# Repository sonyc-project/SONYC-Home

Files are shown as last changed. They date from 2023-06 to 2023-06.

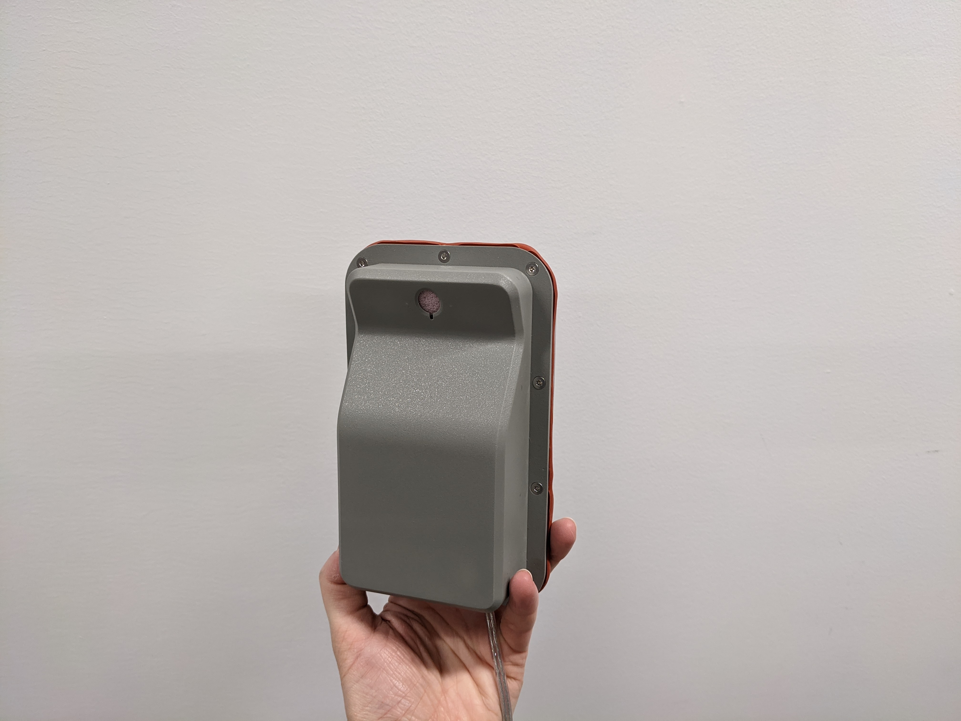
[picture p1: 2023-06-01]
Hardware/History/Assembly Photos/PXL_20201028_211720982.jpg

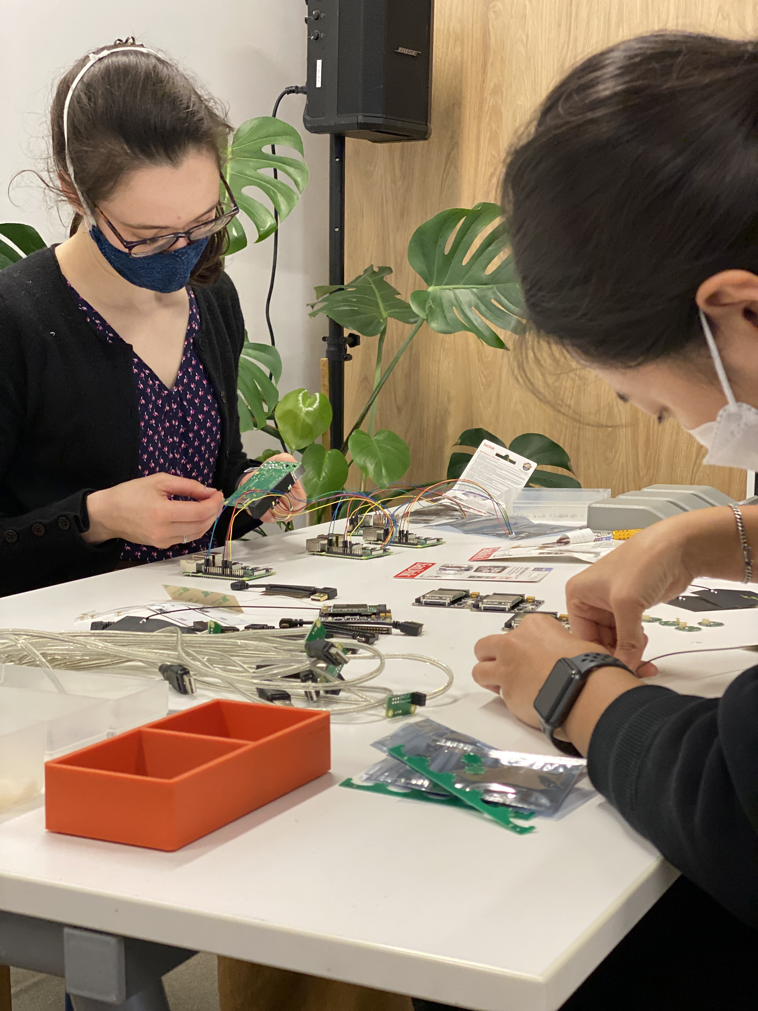
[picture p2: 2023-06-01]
Hardware/History/Assembly Photos/IMG_3674.jpeg

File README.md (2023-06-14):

# SONYC Home Project Summary
The SONYC Home project aims to address the issue of urban noise pollution, which poses a threat to the quality of life and public health of urban inhabitants. The World Health Organization (WHO) has documented various adverse health effects caused by noise pollution, including hearing impairment, interference with speech communication, disturbance of rest and sleep, mental health and performance effects, residential behavior and annoyance, and interference with intended activities.

In New York City (NYC), noise is monitored through the 311 civil complaint service, which has received close to 5 million noise-related complaints to date, outnumbering any other complaint type. However, this service has limitations in terms of validating and resolving complaints in a timely manner due to resource constraints and the transient nature of noise sources.

To address these challenges, the SONYC Home project has developed a solution that involves deploying a fleet of noise sensors on the exteriors of NYC residents' windows. These sensors provide accurate decibel measurements, utilize machine learning algorithms for sound source identification, and enhance noise reporting to city agencies responsible for enforcing noise regulations. Residents can interact with the sensor data through an app, which includes visualizations of decibel data over time and allows for human-in-the-loop machine learning.

The deployment of sensor networks in urban settings presents technical and logistical challenges. The SONYC Home sensors rely on existing power outlets and utilize LTE cellular connectivity to overcome limitations in power and networking infrastructure. Mounting the sensors on residential windows allows for proximity to complainants and easy access to power outlets.

The ideal domestic noise monitoring sensor for the SONYC Home project should have features such as simple deployment, unintrusiveness, low maintenance, weather resistance, data privacy, accessible data insights/visualization, and user interactivity.

The SONYC Home sensor network consists of remote acoustic sensors deployed outside the apartments of participants with noise issues. These sensors transmit data to central servers, where it is securely stored and made available to users and relevant city agencies through web browsers. The sensor design prioritizes usability and utility, with a single board computer, cellular connectivity, custom calibrated acoustic front-end, and a custom housing with a heat sink to address overheating issues.

The mounting of the sensors is designed to be user-friendly, allowing users to easily mount the devices on their windows with adhesive strips. The sensors undergo physical stress testing to ensure they can withstand environmental conditions and remain securely mounted. The sensors are equipped with a custom microphone board, featuring a high-performance digital MEMS microphone that captures the full frequency range of urban sound. The microphone is calibrated for accuracy, and measures are taken to protect it from water damage.

The software running on the SONYC Home sensors extracts relevant information from the environment, including overall sound level and machine learning classifications. The collected audio samples are used for identification purposes and can contribute to the development of advanced machine learning algorithms. Privacy is maintained by sparse sampling of audio and ensuring conversations cannot be reconstructed.

Overall, the SONYC Home project provides a comprehensive solution for monitoring and mitigating urban noise issues, combining advanced sensor technology, machine learning, and user engagement to improve the quality of life for urban inhabitants.

This repository is a centralized hub for all resources related to the project. It consists of three main directories, each dedicated to a specific component of the system:

### [Hardware](<./Hardware>)
The **Hardware** directory stores hardware design files, including schematics, PCB layouts, and relevant documentation.

### [Node software](<./Node software>)
The **Node software** directory contains firmware, drivers, and software modules for the noise sensor nodes. These components capture noise data, implement machine listening algorithms and transmit it to the central server.

### [Server software](<./Server software>)
The **Server software** directory houses the software components running on the project server. It includes backend infrastructure, data processing algorithms, database management systems, and web interfaces for data visualization and analysis.

**This is all a work in progress so will be updated as this content is compiled**

------------------------------------------------------------------------------------------------------------------------
Shield: [][cc-by-nc-sa]

This work is licensed under a
[Creative Commons Attribution-NonCommercial-ShareAlike 4.0 International License][cc-by-nc-sa].

[][cc-by-nc-sa]

[cc-by-nc-sa]: http://creativecommons.org/licenses/by-nc-sa/4.0/
[cc-by-nc-sa-image]: https://licensebuttons.net/l/by-nc-sa/4.0/88x31.png
[cc-by-nc-sa-shield]: https://img.shields.io/badge/License-CC%20BY--NC--SA%204.0-lightgrey.svg

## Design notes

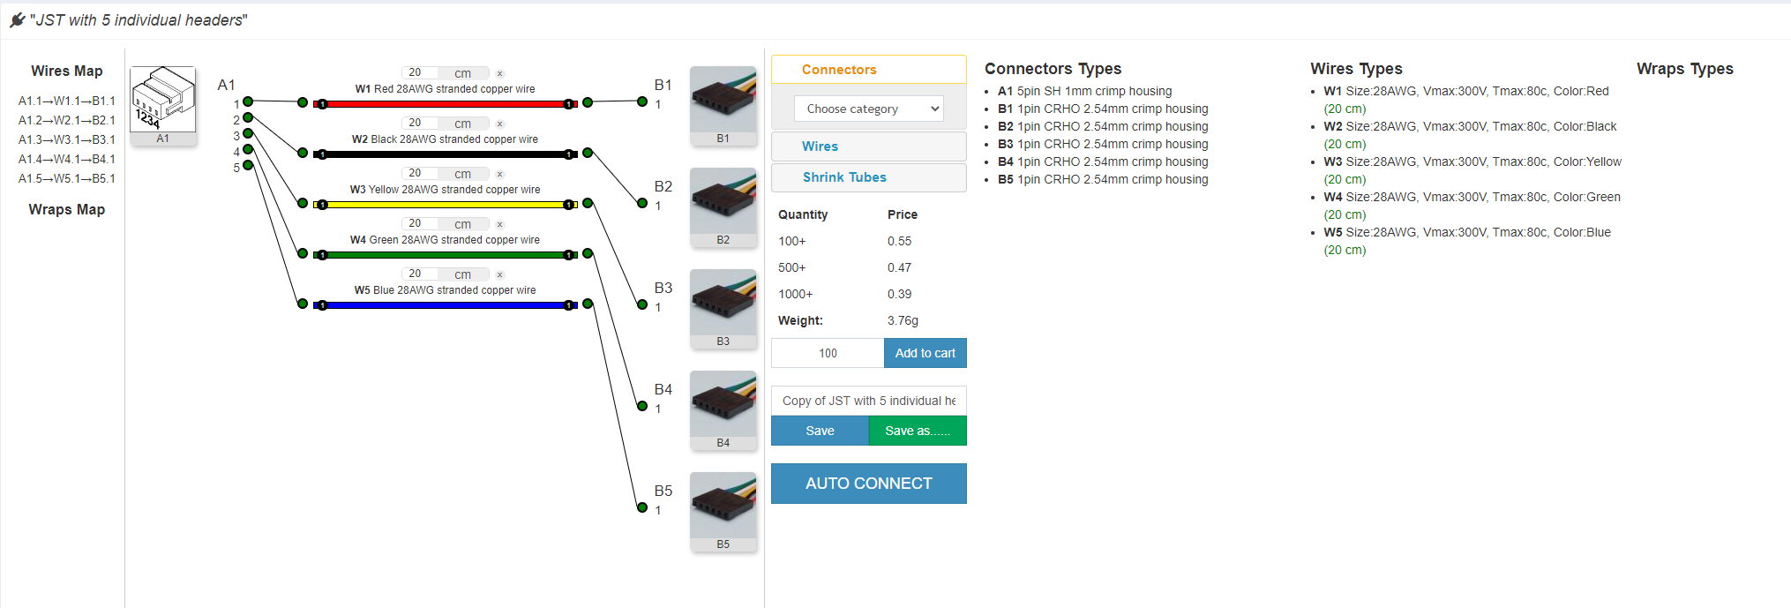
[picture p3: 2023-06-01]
Hardware/Design Files/Drawings/Mic-Cable-custom.png

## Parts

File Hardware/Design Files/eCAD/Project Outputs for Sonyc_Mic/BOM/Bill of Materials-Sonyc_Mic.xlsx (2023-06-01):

Designator | Quantity | Description | Comment | Value | Voltage | Footprint
C1 | 1 | CAP 0402 CERAMIC 100n 16V ±10% X7R | 100n | 100n | 16V | 0402CAP
CN1 | 1 | JST Connector Header Surface Mount 5 position 0.039" (1.00mm) | BM05B-SRSS-TB |  |  | CON5_BM05B-SRSS-TB
MK1 | 1 | MICROPHONE MEMS DIGITAL I2S OMNI | ICS43432 | ICS43432 |  | ICS43432
R1, R2, R3 | 3 | RES 0402 0.063W ±1% THICK FILM | 15R | 15R | 50V | 0402 | REPLACE WITH 0ohm resistor!

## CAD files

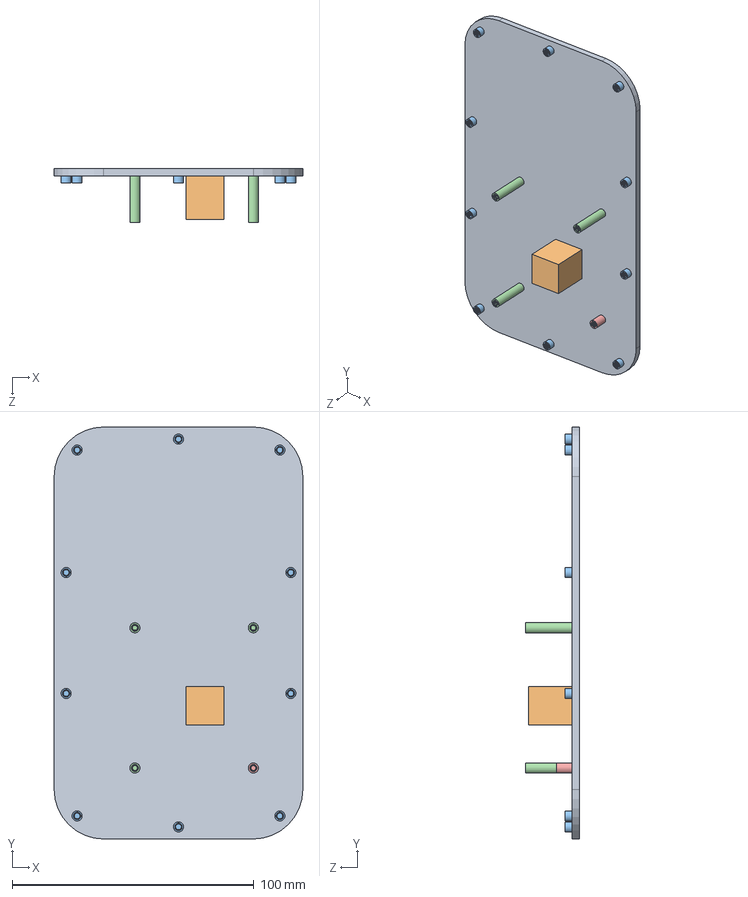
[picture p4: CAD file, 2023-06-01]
Hardware/Design Files/Solidworks CAD/SONYC-SW-database/BACK-PLATE-ASSEMBLY.SLDASM
102.9 x 170.4 x 22.2 mm
Back-Plate
SONYC-Heat-sink-block
93090A571_PRESS-FIT FEMALE ROUND STANDOFFS x 10
93090A554_PRESS-FIT FEMALE ROUND STANDOFFS x 3
93090A430_PRESS-FIT FEMALE ROUND STANDOFFS

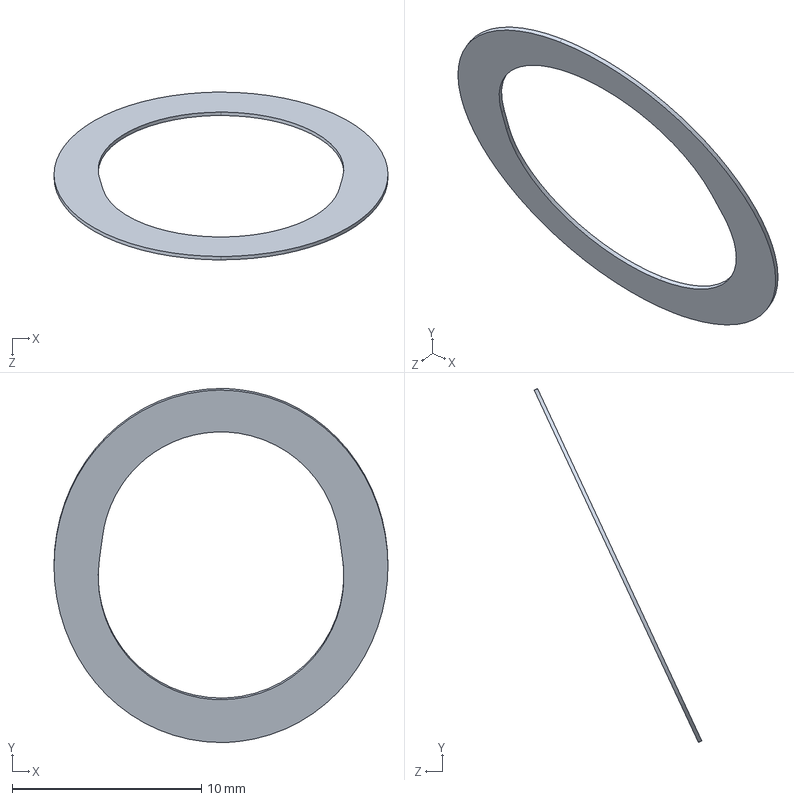
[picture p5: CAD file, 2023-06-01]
Hardware/Design Files/STEP files/SONYC-Porelle-membrane rev1.STEP
17.6 x 18.7 x 8.87 mm

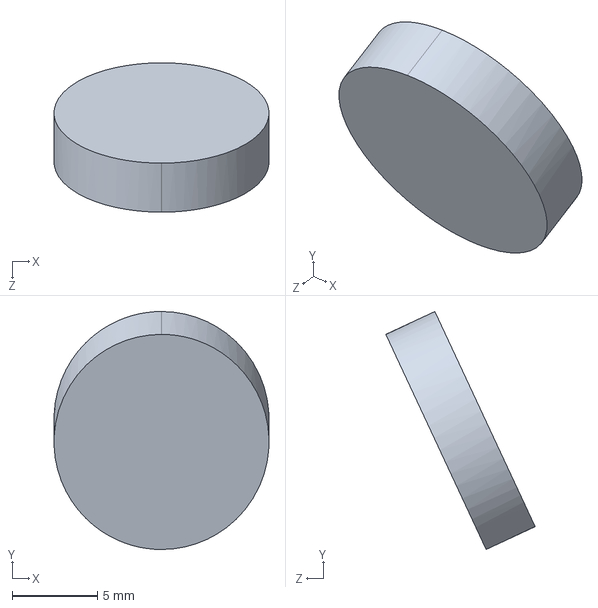
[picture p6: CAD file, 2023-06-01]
Hardware/Design Files/STEP files/SONYC_foam-windscreen rev.STEP
12.6 x 14.0 x 8.76 mm

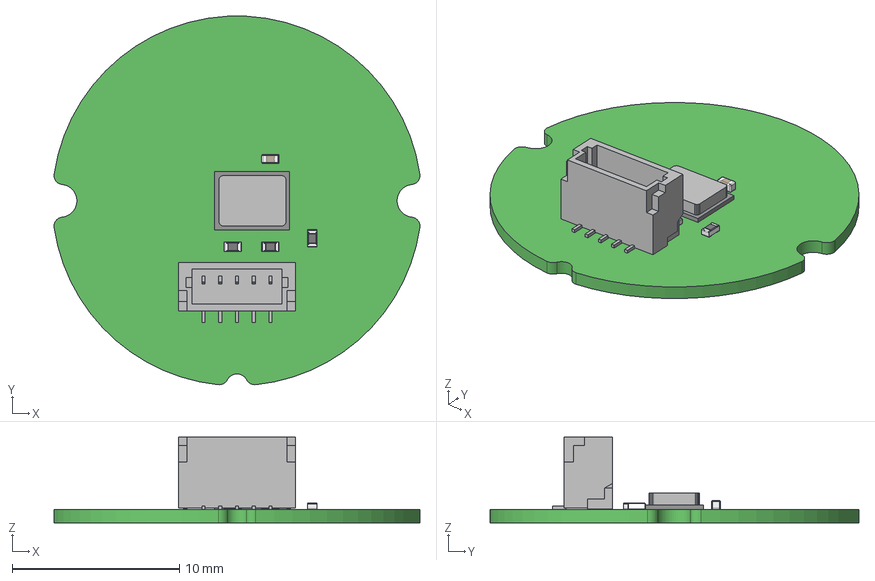
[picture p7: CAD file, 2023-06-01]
Hardware/Design Files/eCAD/Project Outputs for Sonyc_Mic/ExportSTEP/Sonyc_Mic.step
21.9 x 22.0 x 5.13 mm
Extruded x 2
BM05B-SRSS-TB_RGB8421504

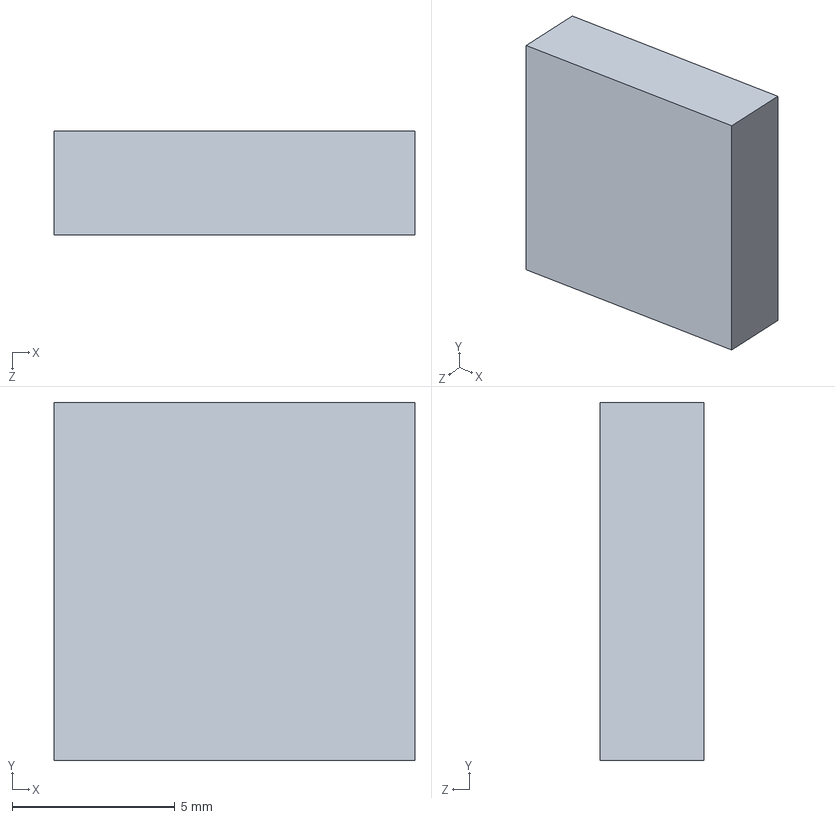
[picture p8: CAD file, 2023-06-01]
Hardware/Design Files/STEP files/SONYC_gasket_power-cable rev.STEP
11.1 x 11.0 x 3.18 mm

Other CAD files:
Hardware/Design Files/STEP files/BACK-PLATE-ASSEMBLY rev4.STEP
Hardware/Design Files/eCAD/Project Outputs for Sonyc_Mic/ExportSTEP/Board.sldasm
Hardware/Design Files/eCAD/Project Outputs for Sonyc_Mic/ExportSTEP/MK1.sldasm
Hardware/Design Files/eCAD/Project Outputs for Sonyc_Mic/ExportSTEP/R2.sldasm
Hardware/Design Files/eCAD/Project Outputs for Sonyc_Mic/ExportSTEP/RESC-0402.sldasm
Hardware/Design Files/eCAD/Project Outputs for Sonyc_Mic/ExportSTEP/R3.sldasm
Hardware/Design Files/eCAD/Project Outputs for Sonyc_Mic/ExportSTEP/CN1.sldasm
Hardware/Design Files/eCAD/Project Outputs for Sonyc_Mic/ExportSTEP/C1.sldasm
Hardware/Design Files/eCAD/Project Outputs for Sonyc_Mic/ExportSTEP/R1.sldasm
Hardware/Design Files/eCAD/Project Outputs for Sonyc_Mic/ExportSTEP/CAPC-0402-T0.55-BN.sldasm
Hardware/Design Files/eCAD/Project Outputs for Sonyc_Mic/AutoCAD PCB/Sonyc_Mic.DWG
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

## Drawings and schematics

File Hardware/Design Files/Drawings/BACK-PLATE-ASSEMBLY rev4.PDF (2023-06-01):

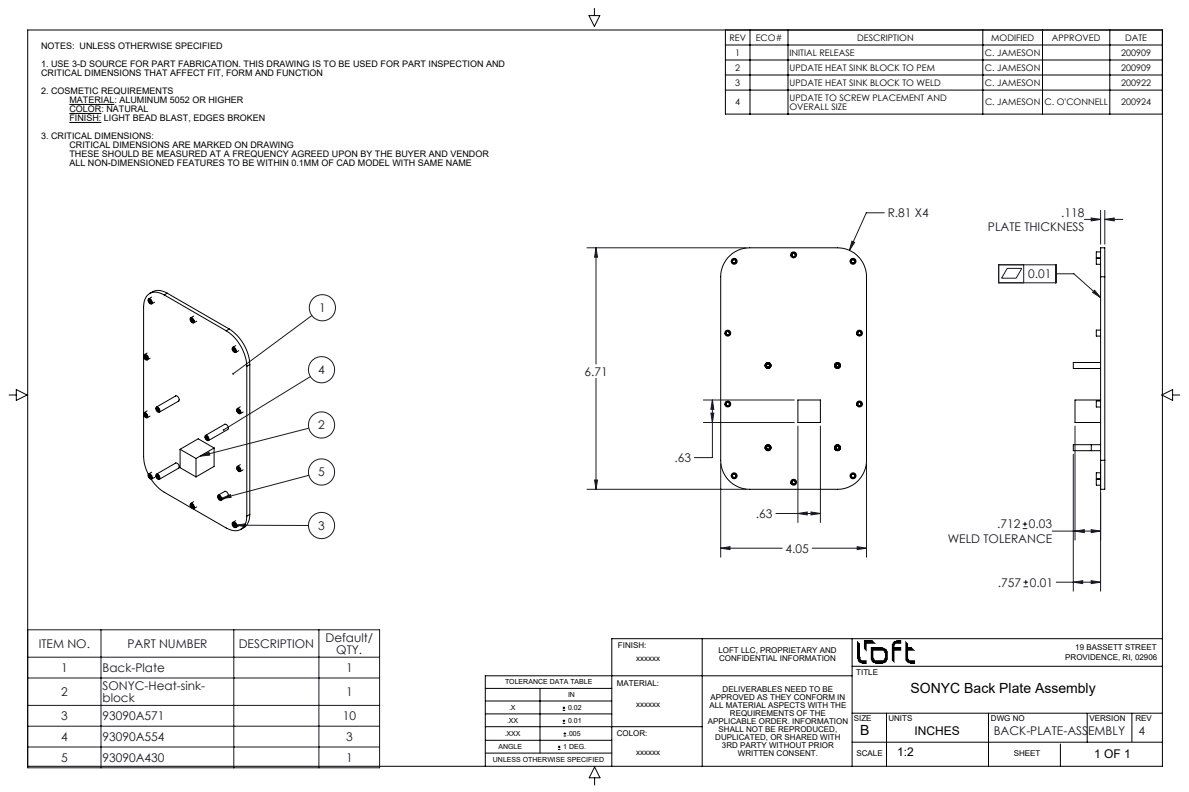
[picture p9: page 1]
WELD TOLERANCE; PLATE THICKNESS; SIZE; UNITS; DWG NO; REV; ANGLE; 1 DEG.; UNLESS OTHERWISE SPECIFIED; 19 BASSETT STREET PROVIDENCE, RI, 02906

REV | ECO# | DESCRIPTION | MODIFIED | APPROVED | DATE
1 | | INITIAL RELEASE | C. JAMESON | | 200909
2 | | UPDATE HEAT SINK BLOCK TO PEM | C. JAMESON | | 200909
3 | | UPDATE HEAT SINK BLOCK TO WELD | C. JAMESON | | 200922
4 | | UPDATE TO SCREW PLACEMENT AND OVERALL SIZE | C. JAMESON | C. O'CONNELL | 200924

NOTES: UNLESS OTHERWISE SPECIFIED
1. USE 3-D SOURCE FOR PART FABRICATION. THIS DRAWING IS TO BE USED FOR PART INSPECTION AND
CRITICAL DIMENSIONS THAT AFFECT FIT, FORM AND FUNCTION
2. COSMETIC REQUIREMENTS
MATERIAL: ALUMINUM 5052 OR HIGHER
COLOR: NATURAL
FINISH: LIGHT BEAD BLAST, EDGES BROKEN
3. CRITICAL DIMENSIONS:
CRITICAL DIMENSIONS ARE MARKED ON DRAWING
THESE SHOULD BE MEASURED AT A FREQUENCY AGREED UPON BY THE BUYER AND VENDOR
ALL NON-DIMENSIONED FEATURES TO BE WITHIN 0.1MM OF CAD MODEL WITH SAME NAME

ITEM NO. | PART NUMBER | DESCRIPTION | Default/ QTY.
1 | Back-Plate | | 1
2 | SONYC-Heat-sink-block | | 1
3 | 93090A571 | | 10
4 | 93090A554 | | 3
5 | 93090A430 | | 1

LOFT LLC, PROPRIETARY AND
CONFIDENTIAL INFORMATION

TITLE
SONYC Back Plate Assembly

TOLERANCE DATA TABLE

DELIVERABLES NEED TO BE
APPROVED AS THEY CONFORM IN
ALL MATERIAL ASPECTS WITH THE
REQUIREMENTS OF THE
APPLICABLE ORDER. INFORMATION
SHALL NOT BE REPRODUCED,
DUPLICATED, OR SHARED WITH
3RD PARTY WITHOUT PRIOR
WRITTEN CONSENT.

BACK-PLATE-ASSEMBLY 4

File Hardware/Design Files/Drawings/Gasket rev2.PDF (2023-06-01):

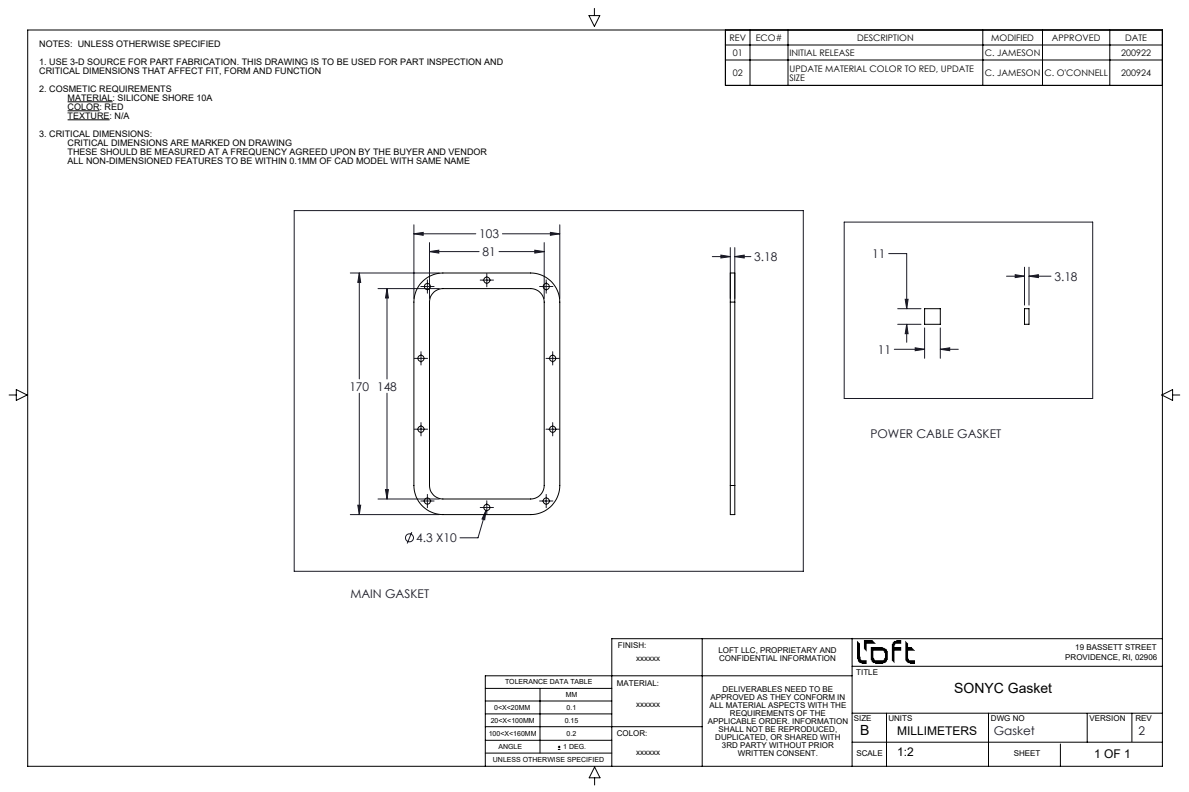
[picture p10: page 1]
MAIN GASKET; SIZE; UNITS; DWG NO; REV; SONYC Gasket; ANGLE; 1 DEG.; UNLESS OTHERWISE SPECIFIED; 19 BASSETT STREET PROVIDENCE, RI, 02906

REV | ECO# | DESCRIPTION | MODIFIED | APPROVED | DATE
01 | | INITIAL RELEASE | C. JAMESON | | 200922
02 | | UPDATE MATERIAL COLOR TO RED, UPDATE SIZE | C. JAMESON | C. O'CONNELL | 200924

NOTES: UNLESS OTHERWISE SPECIFIED
1. USE 3-D SOURCE FOR PART FABRICATION. THIS DRAWING IS TO BE USED FOR PART INSPECTION AND
CRITICAL DIMENSIONS THAT AFFECT FIT, FORM AND FUNCTION
2. COSMETIC REQUIREMENTS
MATERIAL: SILICONE SHORE 10A
COLOR: RED
TEXTURE: N/A
3. CRITICAL DIMENSIONS:
CRITICAL DIMENSIONS ARE MARKED ON DRAWING
THESE SHOULD BE MEASURED AT A FREQUENCY AGREED UPON BY THE BUYER AND VENDOR
ALL NON-DIMENSIONED FEATURES TO BE WITHIN 0.1MM OF CAD MODEL WITH SAME NAME

POWER CABLE GASKET

LOFT LLC, PROPRIETARY AND
CONFIDENTIAL INFORMATION

TOLERANCE DATA TABLE

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

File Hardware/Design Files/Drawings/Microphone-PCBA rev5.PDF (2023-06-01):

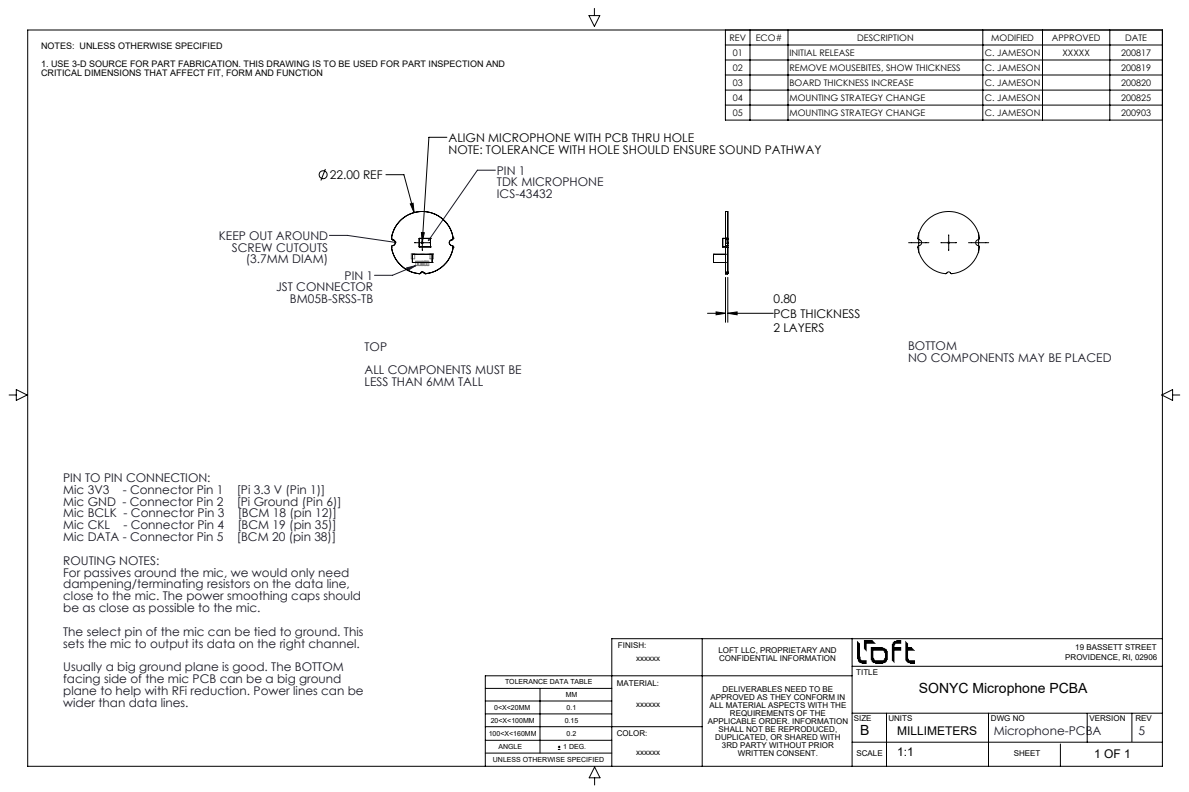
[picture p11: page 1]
22.00 REF; PIN 1; TDK MICROPHONE; PCB THICKNESS 2 LAYERS; SIZE; UNITS; DWG NO; REV; ANGLE; 1 DEG.; UNLESS OTHERWISE SPECIFIED; 19 BASSETT STREET PROVIDENCE, RI, 02906

REV | ECO# | DESCRIPTION | MODIFIED | APPROVED | DATE
01 | | INITIAL RELEASE | C. JAMESON | XXXXX | 200817
02 | | REMOVE MOUSEBITES, SHOW THICKNESS | C. JAMESON | | 200819
03 | | BOARD THICKNESS INCREASE | C. JAMESON | | 200820
04 | | MOUNTING STRATEGY CHANGE | C. JAMESON | | 200825
05 | | MOUNTING STRATEGY CHANGE | C. JAMESON | | 200903

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

ALIGN MICROPHONE WITH PCB THRU HOLE
NOTE: TOLERANCE WITH HOLE SHOULD ENSURE SOUND PATHWAY

KEEP OUT AROUND
SCREW CUTOUTS
(3.7MM DIAM)
JST CONNECTOR
BM05B-SRSS-TB

TOP
ALL COMPONENTS MUST BE
LESS THAN 6MM TALL

BOTTOM
NO COMPONENTS MAY BE PLACED

PIN TO PIN CONNECTION:
Mic 3V3 - Connector Pin 1 [Pi 3.3 V (Pin 1)]
Mic GND - Connector Pin 2 [Pi Ground (Pin 6)]
Mic BCLK - Connector Pin 3 [BCM 18 (pin 12)]
Mic CKL - Connector Pin 4 [BCM 19 (pin 35)]
Mic DATA - Connector Pin 5 [BCM 20 (pin 38)]
ROUTING NOTES:
For passives around the mic, we would only need
dampening/terminating resistors on the data line,
close to the mic. The power smoothing caps should
be as close as possible to the mic.
The select pin of the mic can be tied to ground. This
sets the mic to output its data on the right channel.
Usually a big ground plane is good. The BOTTOM
facing side of the mic PCB can be a big ground
plane to help with RFi reduction. Power lines can be
wider than data lines.

LOFT LLC, PROPRIETARY AND
CONFIDENTIAL INFORMATION

TOLERANCE DATA TABLE

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

SONYC Microphone PCBA

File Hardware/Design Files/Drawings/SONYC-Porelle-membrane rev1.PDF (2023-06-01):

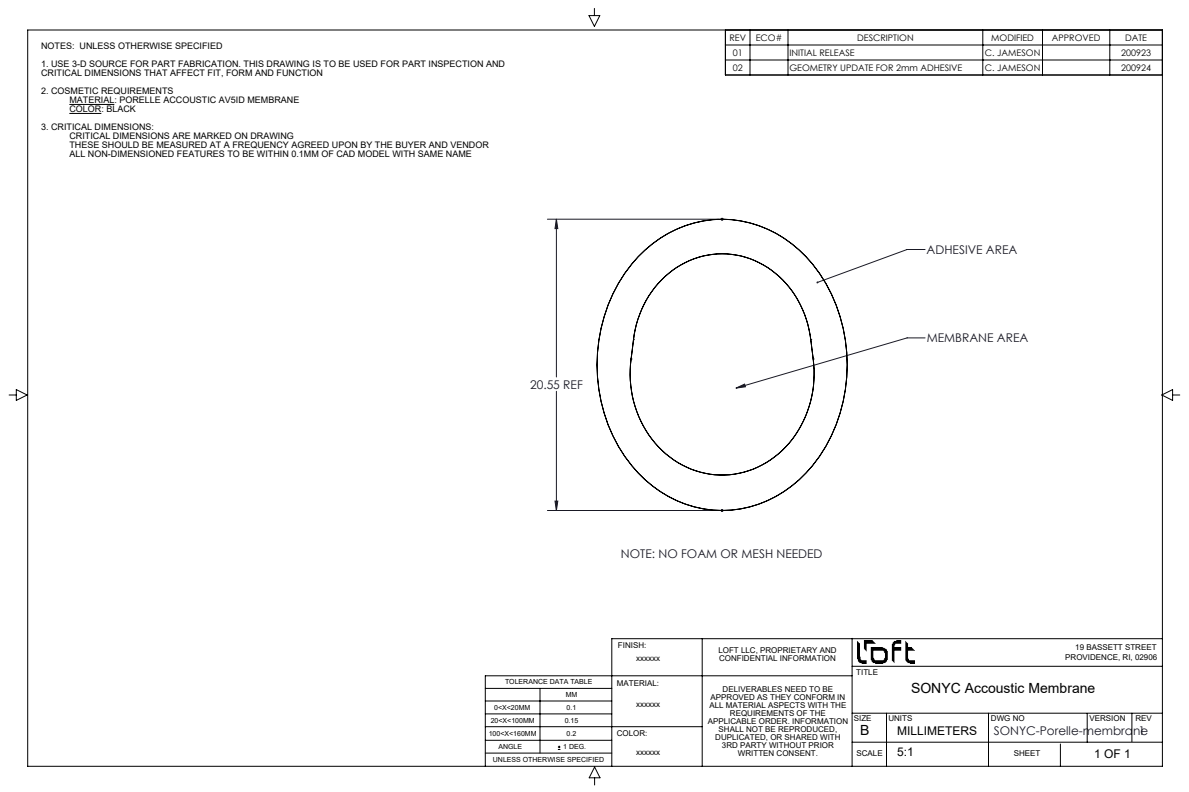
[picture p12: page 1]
20.55 REF; ADHESIVE AREA; MEMBRANE AREA; SIZE; UNITS; DWG NO; REV; ANGLE; 1 DEG.; UNLESS OTHERWISE SPECIFIED; 19 BASSETT STREET PROVIDENCE, RI, 02906

REV | ECO# | DESCRIPTION | MODIFIED | APPROVED | DATE
01 | | INITIAL RELEASE | C. JAMESON | | 200923
02 | | GEOMETRY UPDATE FOR 2mm ADHESIVE | C. JAMESON | | 200924

NOTES: UNLESS OTHERWISE SPECIFIED
1. USE 3-D SOURCE FOR PART FABRICATION. THIS DRAWING IS TO BE USED FOR PART INSPECTION AND
CRITICAL DIMENSIONS THAT AFFECT FIT, FORM AND FUNCTION
2. COSMETIC REQUIREMENTS
MATERIAL: PORELLE ACCOUSTIC AV5ID MEMBRANE
COLOR: BLACK
3. CRITICAL DIMENSIONS:
CRITICAL DIMENSIONS ARE MARKED ON DRAWING
THESE SHOULD BE MEASURED AT A FREQUENCY AGREED UPON BY THE BUYER AND VENDOR
ALL NON-DIMENSIONED FEATURES TO BE WITHIN 0.1MM OF CAD MODEL WITH SAME NAME

NOTE: NO FOAM OR MESH NEEDED

LOFT LLC, PROPRIETARY AND
CONFIDENTIAL INFORMATION

TITLE
SONYC Accoustic Membrane

TOLERANCE DATA TABLE

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

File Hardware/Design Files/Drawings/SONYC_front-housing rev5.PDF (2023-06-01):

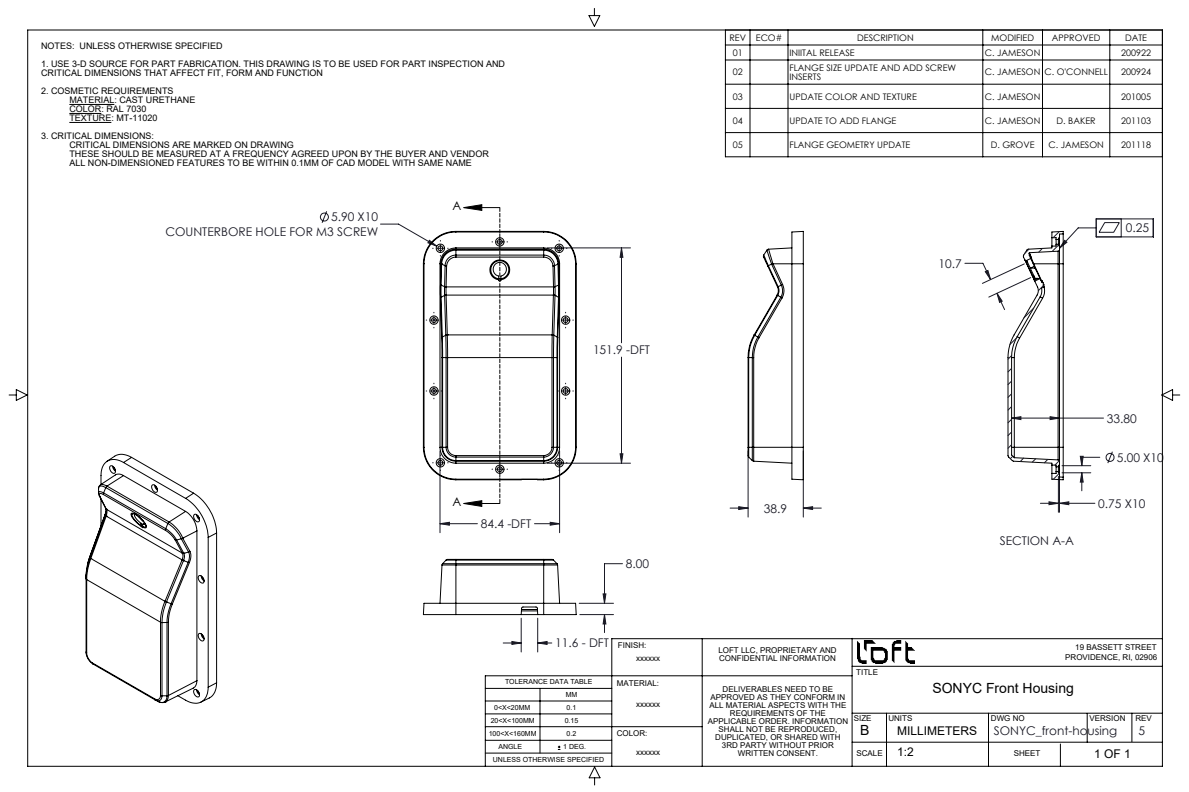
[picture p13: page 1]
84.4 -DFT; 151.9 -DFT; 11.6 - DFT; SECTION A-A; SIZE; UNITS; DWG NO; REV; ANGLE; 1 DEG.; UNLESS OTHERWISE SPECIFIED; 19 BASSETT STREET PROVIDENCE, RI, 02906

REV | ECO# | DESCRIPTION | MODIFIED | APPROVED | DATE
01 | | INIITAL RELEASE | C. JAMESON | | 200922
02 | | FLANGE SIZE UPDATE AND ADD SCREW INSERTS | C. JAMESON | C. O'CONNELL | 200924

NOTES: UNLESS OTHERWISE SPECIFIED
1. USE 3-D SOURCE FOR PART FABRICATION. THIS DRAWING IS TO BE USED FOR PART INSPECTION AND
CRITICAL DIMENSIONS THAT AFFECT FIT, FORM AND FUNCTION
2. COSMETIC REQUIREMENTS
MATERIAL: CAST URETHANE
COLOR: RAL 7030
TEXTURE: MT-11020
3. CRITICAL DIMENSIONS:
CRITICAL DIMENSIONS ARE MARKED ON DRAWING
THESE SHOULD BE MEASURED AT A FREQUENCY AGREED UPON BY THE BUYER AND VENDOR
ALL NON-DIMENSIONED FEATURES TO BE WITHIN 0.1MM OF CAD MODEL WITH SAME NAME

03 | | UPDATE COLOR AND TEXTURE | C. JAMESON | | 201005

04 | | UPDATE TO ADD FLANGE | C. JAMESON | D. BAKER | 201103

05 | | FLANGE GEOMETRY UPDATE | D. GROVE | C. JAMESON | 201118

COUNTERBORE HOLE FOR M3 SCREW

LOFT LLC, PROPRIETARY AND
CONFIDENTIAL INFORMATION

TOLERANCE DATA TABLE

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

SONYC Front Housing

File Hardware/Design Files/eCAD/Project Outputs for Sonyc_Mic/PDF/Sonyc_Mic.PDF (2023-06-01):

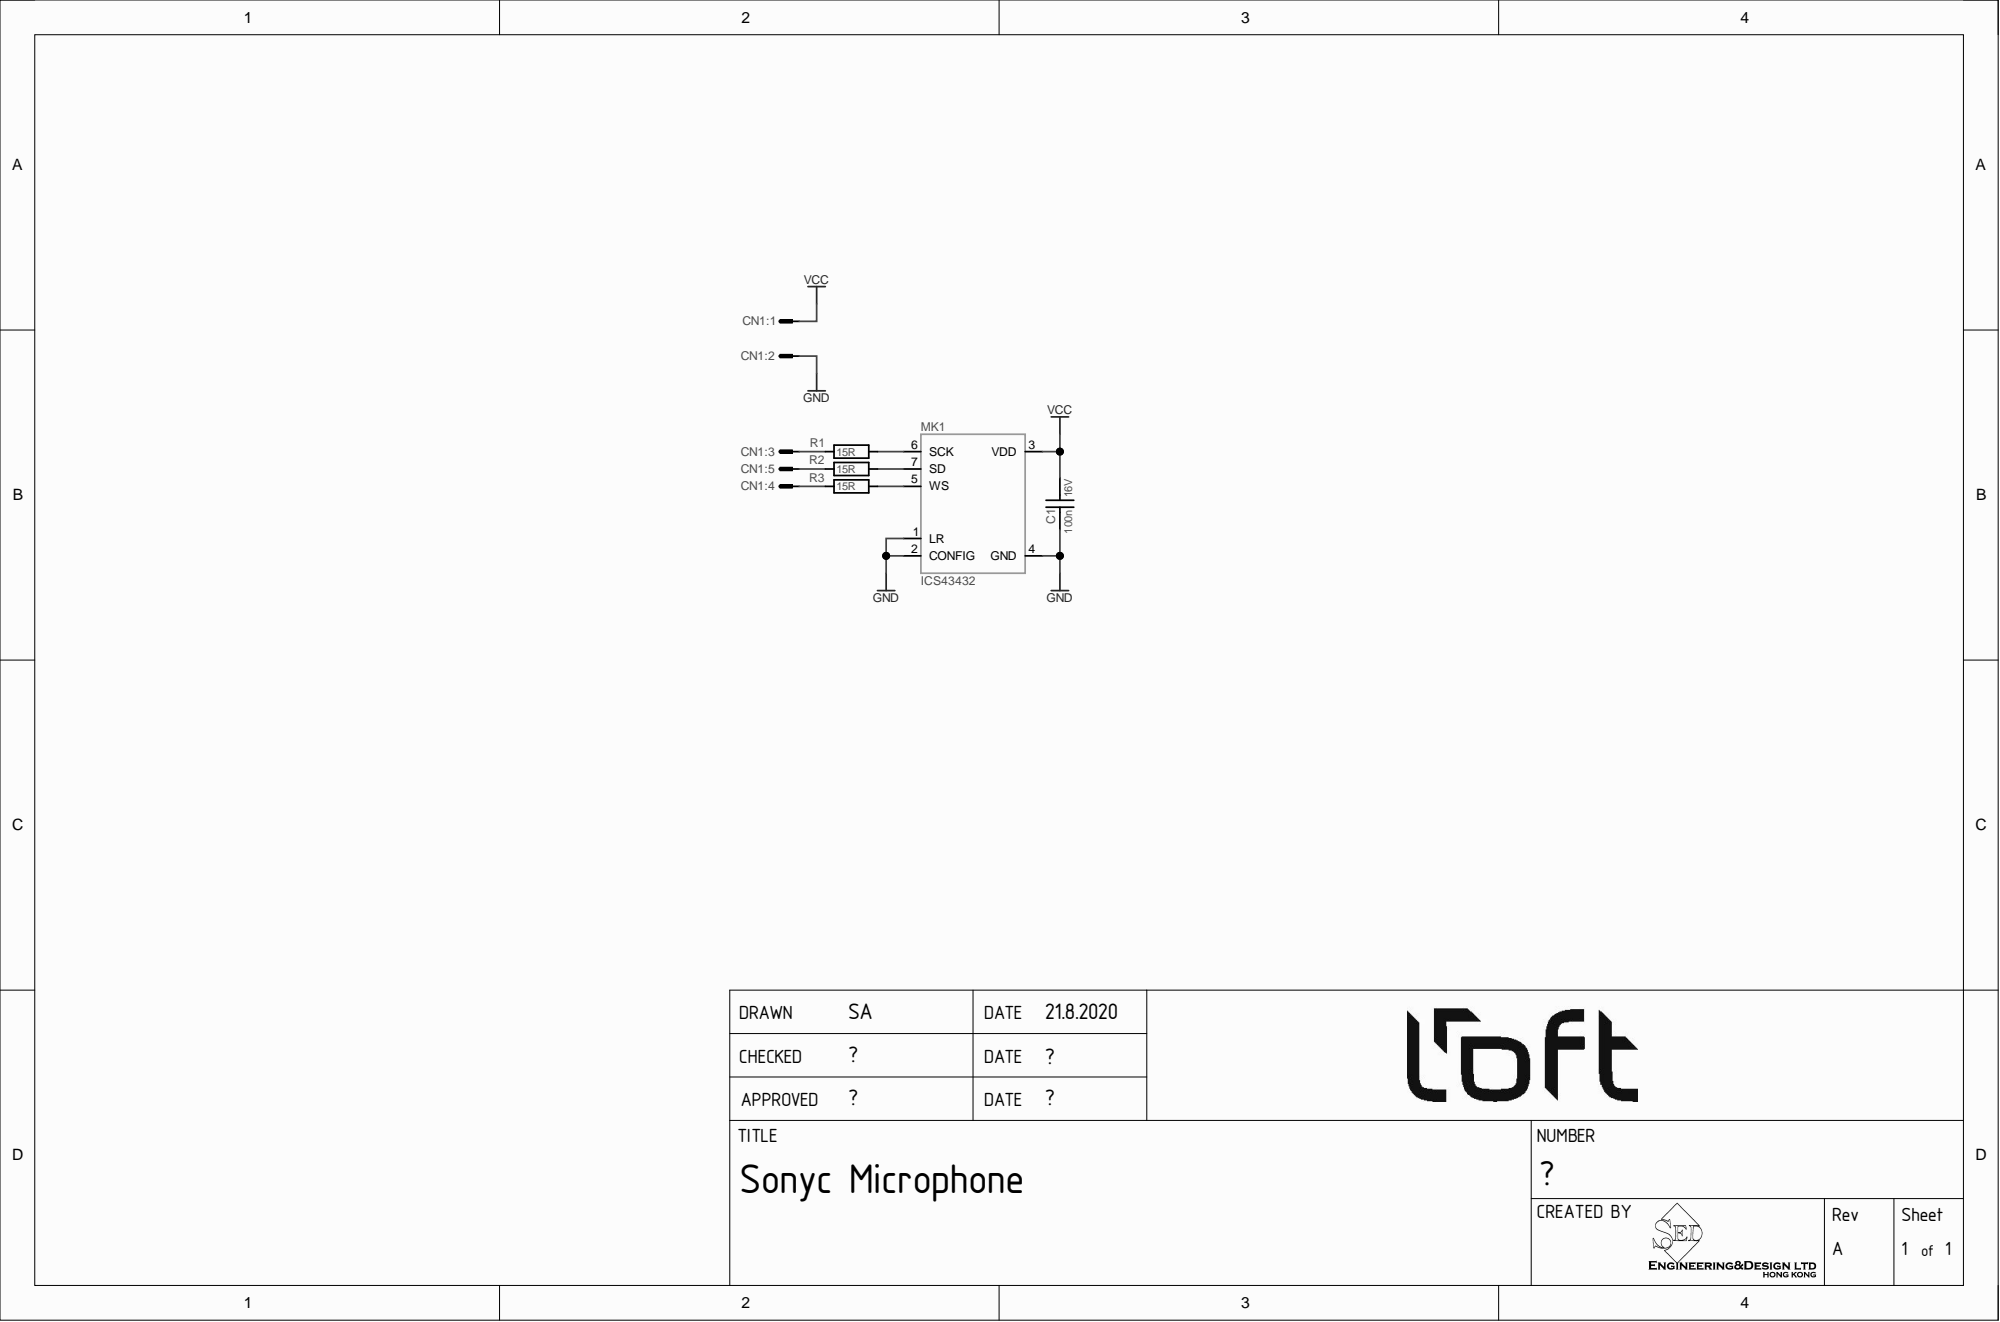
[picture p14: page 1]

SA DRAWN | 21.8.2020 DATE

? CHECKED | DATE ?

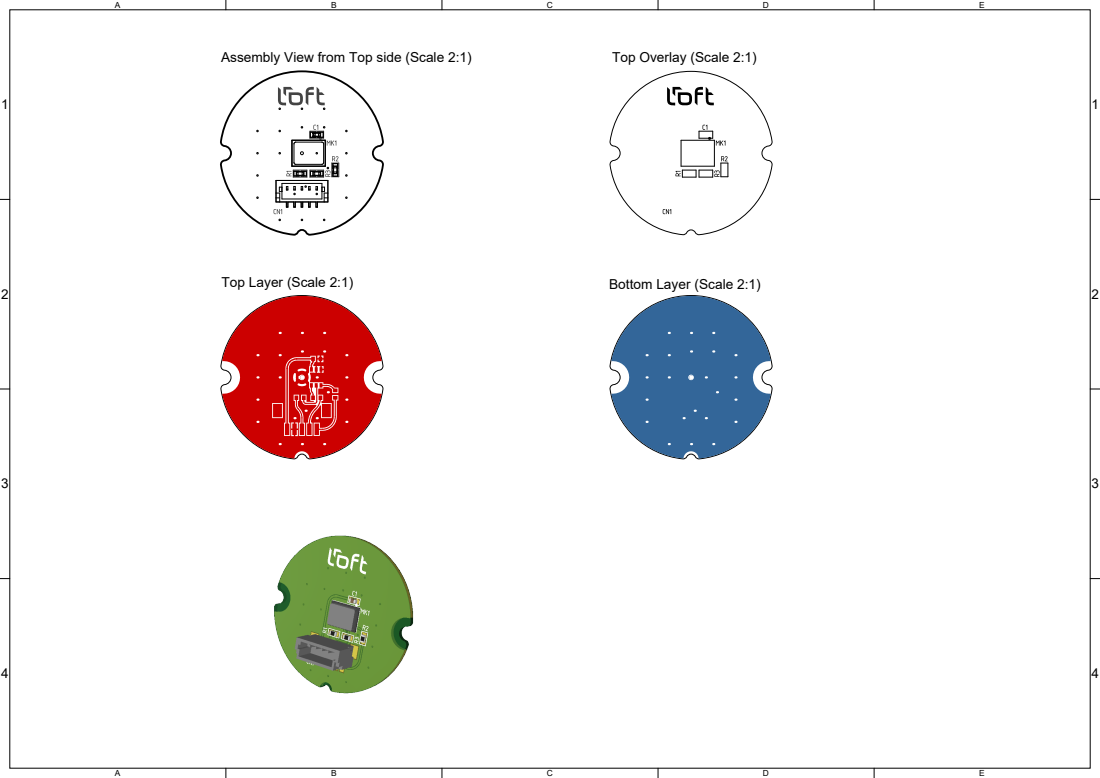
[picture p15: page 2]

Assembly View from Top side (Scale 2:1)

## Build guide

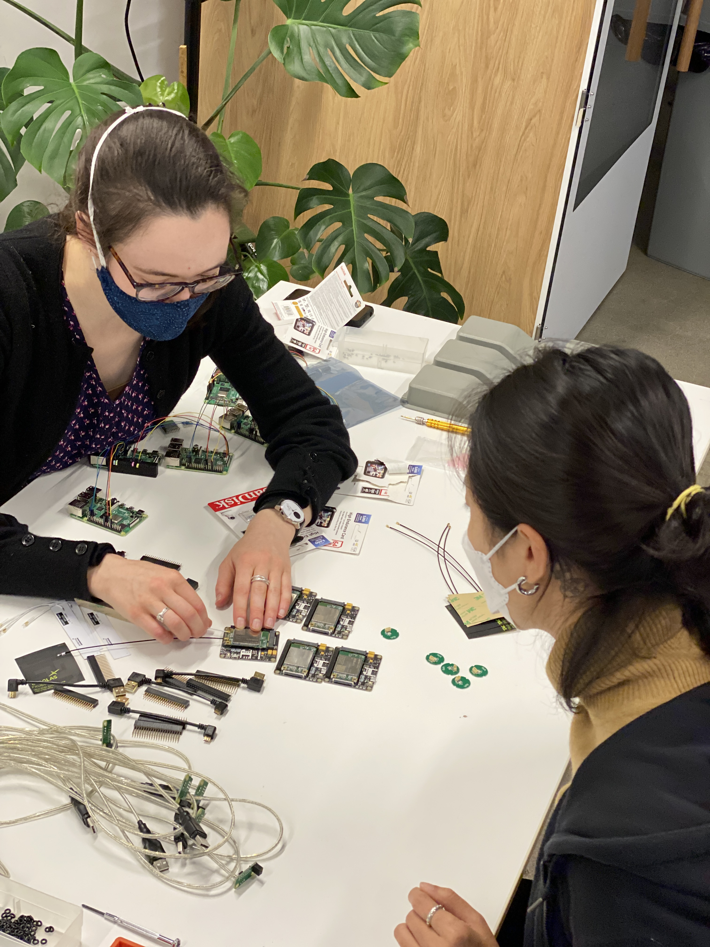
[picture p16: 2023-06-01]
Hardware/History/Assembly Photos/IMG_3671.jpeg

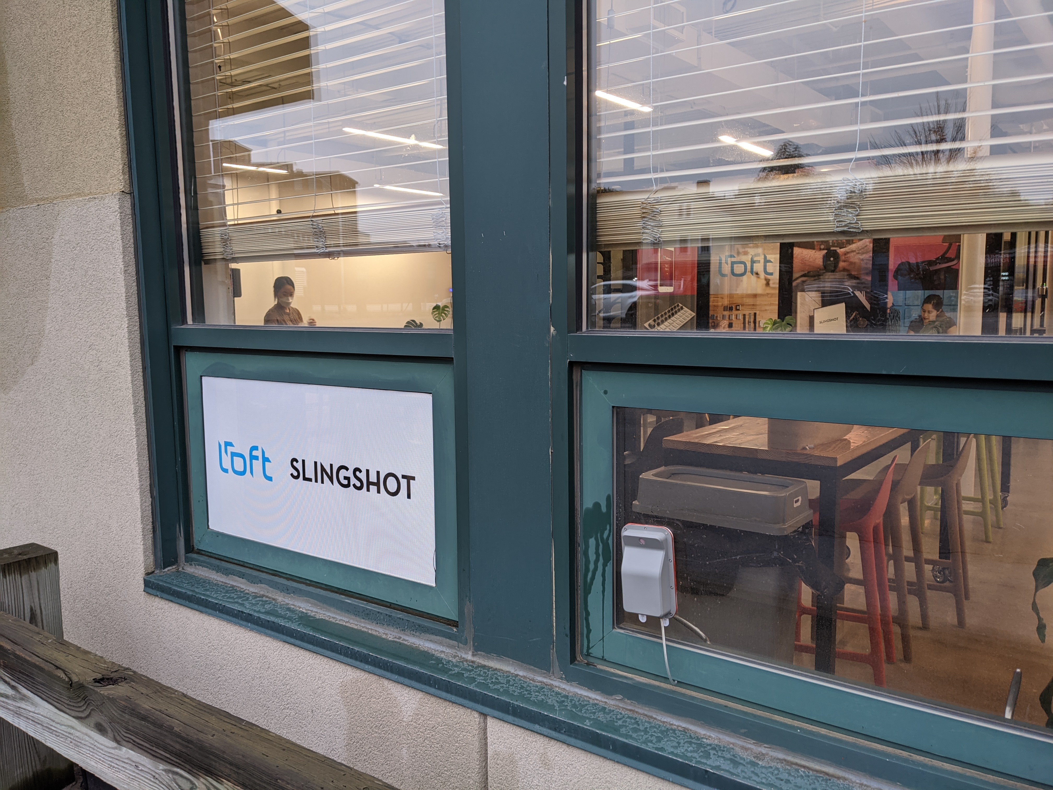
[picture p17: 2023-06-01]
Hardware/History/Assembly Photos/PXL_20201028_205839294.jpg

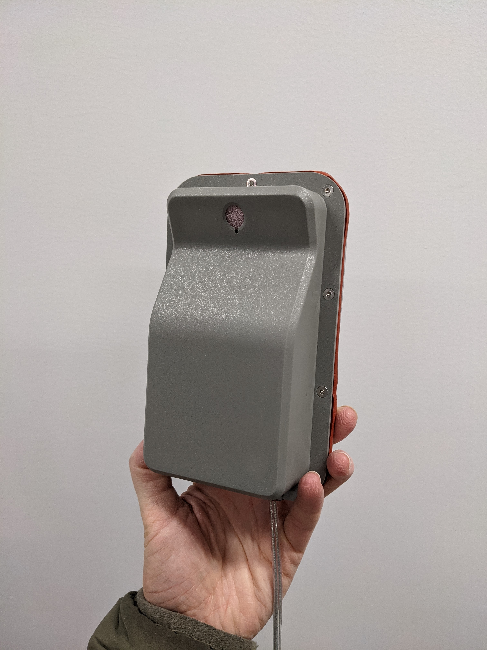
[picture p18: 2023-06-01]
Hardware/History/Assembly Photos/PXL_20201028_211632010.jpg

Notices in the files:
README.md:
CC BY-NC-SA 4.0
